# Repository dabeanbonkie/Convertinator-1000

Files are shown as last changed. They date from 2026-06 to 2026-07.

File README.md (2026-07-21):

# Convertinator 1000 Showcase

Convertinator Zine

# Description
The Convertinator 1000 is a basic power supply that converts voltage from a USB-C (5V) to 1.2V, 3.3V, 12V & 24V, also featuring an output for 5V. It has the input as the USB-C and the outputs as dupont headers as its main use is for prototyping small cicuits and basic breadboarding. It isnt made to handle strong current but the 12V & 24V connections should be able to handle a bit more.

# Reason
I designed this as a project that i could maybe use in the future when doing smaller projects as i get more and more proficient in hardware. Its not intended to run anything too heavy but can handle basic circuitly which is all I would need it for. It also worked perfectly as a project to do while parts for other projects were printing.

# Usage
To use the Convertinator 1000, take a USB-C plugged into any socket (as long as it supplies 5V) and plug it into the USB-C component on the Convertinator 1000. From there, take two dupont wires and connect them to the two headers for each voltage. One header is for the output voltage which on each connection is the header on the left, and the other is the ground which is always on the right. I highly advise you NOT to run anything above 1A on the 1.2V, 3.3V & 5V headers and NOT anything above 1.8A on the 12V & 24V headers.

# Assembly
Putting all the parts together is easy as can be. Since i figured this power supply wouldnt be moving much i havent mounted the pcb. So to assemble the Convertinator 1000, just print both components, put the pcb in the shell making sure all the gubbins on the bottom of the pcb cleanly fit into the groves on the bottom of the shell. Then mount the lid to the shell using a simple nut and bolt (4.8 mm) on the mounting holes on both parts. Then its all complete.

Here is how the pcb should be placed from the bottom of the shell:



# PCB schematic



# PCB editor 



# Onshape Link
https://cad.onshape.com/documents/8818f429682032fa239a6543/w/3c67bc1c1aed2304218f7515/e/04401e7b527ba54e698f04d5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

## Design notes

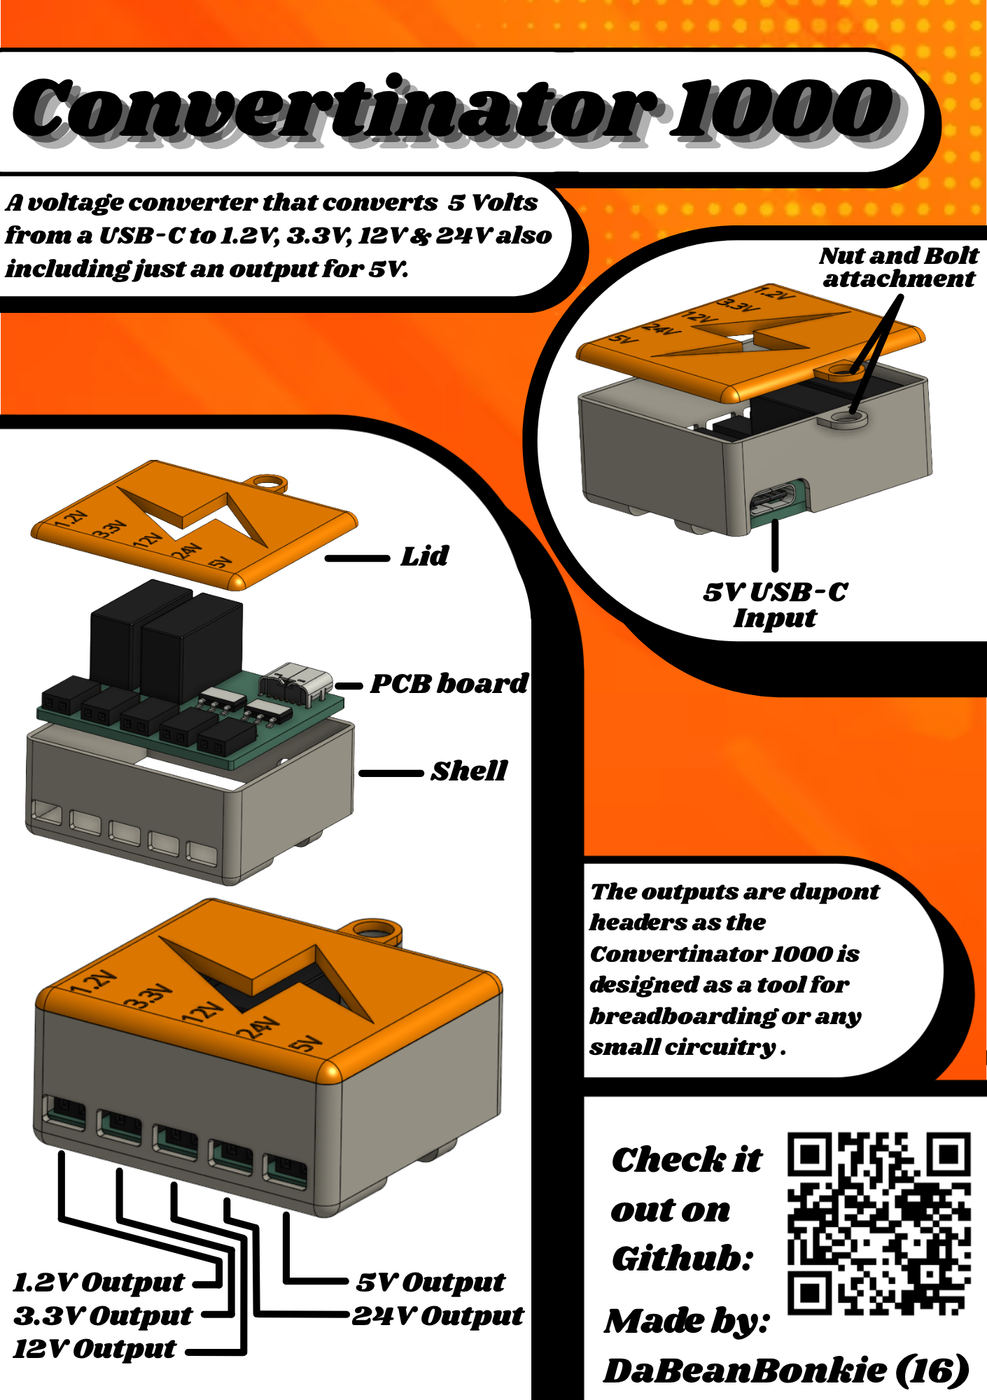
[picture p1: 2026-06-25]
Convertinator Zine.png

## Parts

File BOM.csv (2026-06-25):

Reference | Qty | Value | DNP | Exclude from BOM | Exclude from Board | Footprint | Datasheet | LCSC Link | unit price | price for all units | Total cost of pcb production (JLCPCB)
C4,C5 | 2 | C |  |  |  | Capacitor_SMD:C_0201_0603Metric | https://www.lcsc.com/datasheet/C25054.pdf | https://www.lcsc.com/product-detail/C25054.html?s_z=n_q_0201WMJ010JTEE | $ 0.001 | $ 0.002
J1 | 1 | USB_C_Receptacle_PowerOnly_6P |  |  |  | Connector_USB:USB_C_Receptacle_GCT_USB4125-xx-x-0190_6P_TopMnt_Horizontal | https://www.usb.org/sites/default/files/documents/usb_type-c.zip | https://www.lcsc.com/product-detail/C2988369.html?s_z=n_q_t_usb%2520c%2520female | $0.0864 | $0.0864,
J2,J3,J5,J6,J7 | 5 | Conn_01x02_Socket |  |  |  | Connector_PinSocket_2.54mm:PinSocket_1x02_P2.54mm_Horizontal |  | https://www.lcsc.com/product-detail/C49661.html?s_z=n_q_C49661&globalKeyword=C49661 | $ 0.0642 | 0.321,
U1 | 1 | AMS1117-3.3 |  |  |  | Package_TO_SOT_SMD:SOT-223-3_TabPin2 | http://www.advanced-monolithic.com/pdf/ds1117.pdf | https://www.lcsc.com/product-detail/C6186.html?s_z=n_q_AMS1117-3.3 | $ 0.1994 | $ 0.1994,
U4 | 1 | TMR_1-0512 |  |  |  | Converter_DCDC:Converter_DCDC_TRACO_TMR-1-xxxx_Single_THT | https://www.tracopower.com/sites/default/files/products/datasheets/tmr1_datasheet.pdf | https://www.lcsc.com/product-detail/C5962267.html?s_z=n_q_TMR_1-0512 | $ 13.8133 | $13.8133,
U5 | 1 | TMR_1-0515 |  |  |  | Converter_DCDC:Converter_DCDC_TRACO_TMR-1-xxxx_Single_THT | https://www.tracopower.com/sites/default/files/products/datasheets/tmr1_datasheet.pdf | https://www.lcsc.com/product-detail/C7362911.html?s_z=n_q_TMR_1-0515 | $ 22.9930 | $ 22.9930,
U6 | 1 | AP7361C-12E |  |  |  | Package_TO_SOT_SMD:SOT-223-3_TabPin2 | https://www.diodes.com/assets/Datasheets/AP7361C.pdf | https://www.lcsc.com/product-detail/C7076956.html?s_z=n_q_AP7361C-12E | $ 0.2738 | $ 0.2738,
Full PCB (Populated) |  |  |  |  |  |  |  |  |  |  | $127.01

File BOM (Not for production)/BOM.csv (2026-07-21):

Designator | Footprint | Quantity | Value | Unit cost | Total cost | Total cost (after tax) | LCSC Part # | LCSC Link | Cost PCB SMD JLCPCB (without TMR_1-0515) | Total Cost PCB Production
C4, C5 | 402 | 2 | C | $ 0.0342 | $ 1.71 | $0.80 | C1691 | https://www.lcsc.com/product-detail/C1691.html?s_z=n_q_CL10A106MQ8NNNC
J1 | USB_C_Receptacle_GCT_USB4125-xx-x-0190_6P_TopMnt_Horizontal | 1 | USB_C_Receptacle_PowerOnly_6P | $ 0.9285 | $ 0.93 | $1.13 | C3151650 | https://www.lcsc.com/product-detail/C3151650.html?s_z=n_q_x_USB4125-GF-A
J2, J3, J5, J6, J7 | PinSocket_1x02_P2.54mm_Horizontal | 5 | Conn_01x02_Socket | $ 0.1327 | $ 0.66 | $0.80 | C49326035 | https://www.lcsc.com/product-detail/C49326035.html?s_z=n_q_BX-PM2.54-1-2PWZ
R1, R2 | 402 | 2 | R | $0.0068 | $0.68 | $0.82 | C25905 | https://www.lcsc.com/product-detail/C25905.html?s_z=n_q_0402WGF5101TCE
U1 | SOT-223-3_TabPin2 | 1 | AMS1117-3.3 | $ 0.2004 | $ 1.00 | $ 1.21 | C6186 | https://www.lcsc.com/product-detail/C6186.html?s_z=n_q_AMS1117-3.3
U4 | Converter_DCDC_TRACO_TMR-1-xxxx_Single_THT | 1 | TMR_1-0512 | $ 13.8133 | $ 13.8133 | $16.71 | C5962267 | https://www.lcsc.com/product-detail/C5962267.html?s_z=n_q_TMR_1-0512
U5 | Converter_DCDC_TRACO_TMR-1-xxxx_Single_THT | 1 | TMR_1-0515 | $ 22.9930 | $ 22.9930 | $27.82 | C7362911 | https://www.lcsc.com/product-detail/C7362911.html?s_z=n_q_TMR_1-0515
U6 | SOT-223-3_TabPin2 | 1 | AP7361C-12E | $ 0.2738 | $ 1.37 | $1.66 | C7076956 | https://www.lcsc.com/product-detail/C7076956.html?s_z=n_q_AP7361C-12E
PCB (no TMR_1-0515) |  |  |  |  |  |  |  |  | $111.46
PCB (Complete) |  |  |  |  |  |  |  |  |  | $134.45

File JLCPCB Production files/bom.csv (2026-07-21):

Designator | Footprint | Quantity | Value | LCSC Part #
C4, C5 | 0402 | 2 | C
J1 | USB_C_Receptacle_GCT_USB4125-xx-x-0190_6P_TopMnt_Horizontal | 1 | USB_C_Receptacle_PowerOnly_6P
J2, J3, J5, J6, J7 | PinSocket_1x02_P2.54mm_Horizontal | 5 | Conn_01x02_Socket
R1, R2 | 0402 | 2 | R
U1 | SOT-223-3_TabPin2 | 1 | AMS1117-3.3
U4 | Converter_DCDC_TRACO_TMR-1-xxxx_Single_THT | 1 | TMR_1-0512
U5 | Converter_DCDC_TRACO_TMR-1-xxxx_Single_THT | 1 | TMR_1-0515
U6 | SOT-223-3_TabPin2 | 1 | AP7361C-12E

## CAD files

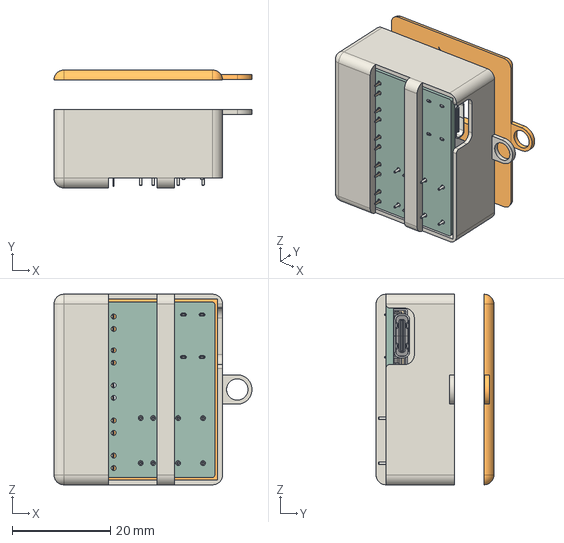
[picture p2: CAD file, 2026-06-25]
Convertinator 1000 STEP file/Convertinator 1000.step
40.3 x 24.0 x 38.8 mm

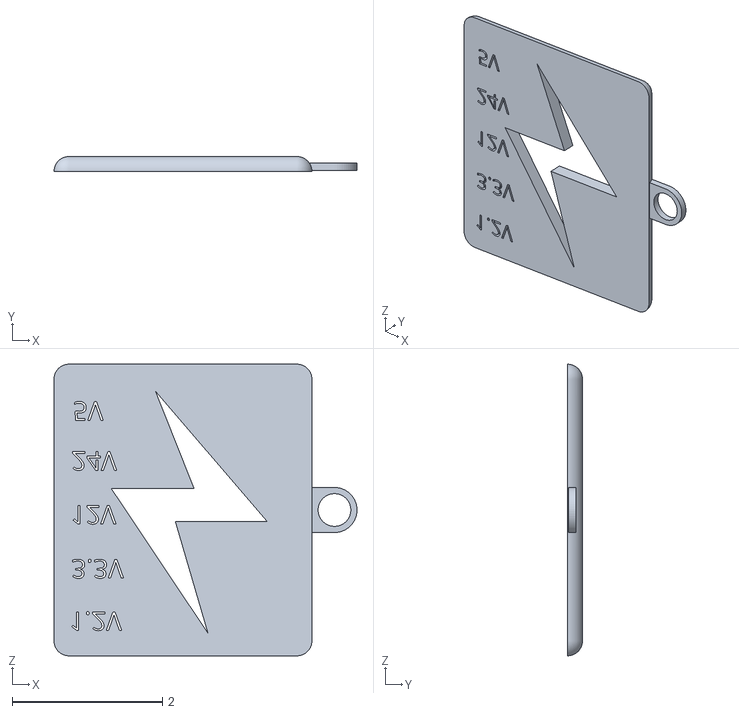
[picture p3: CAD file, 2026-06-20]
Convertinator 1000 STL Files/Top-lid-Convertinator-1000.stl
4.03 x 0.2 x 3.88

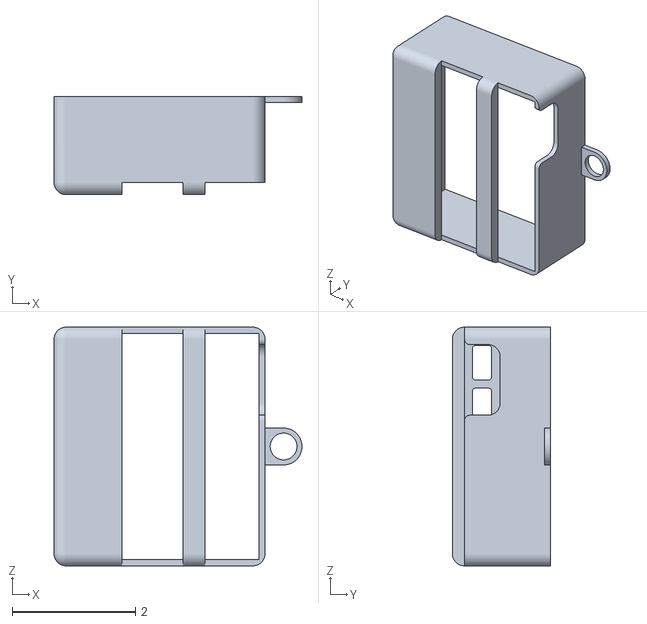
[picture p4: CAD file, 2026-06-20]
Convertinator 1000 STL Files/Shell-Convertinator-1000.stl
4.03 x 1.60 x 3.88

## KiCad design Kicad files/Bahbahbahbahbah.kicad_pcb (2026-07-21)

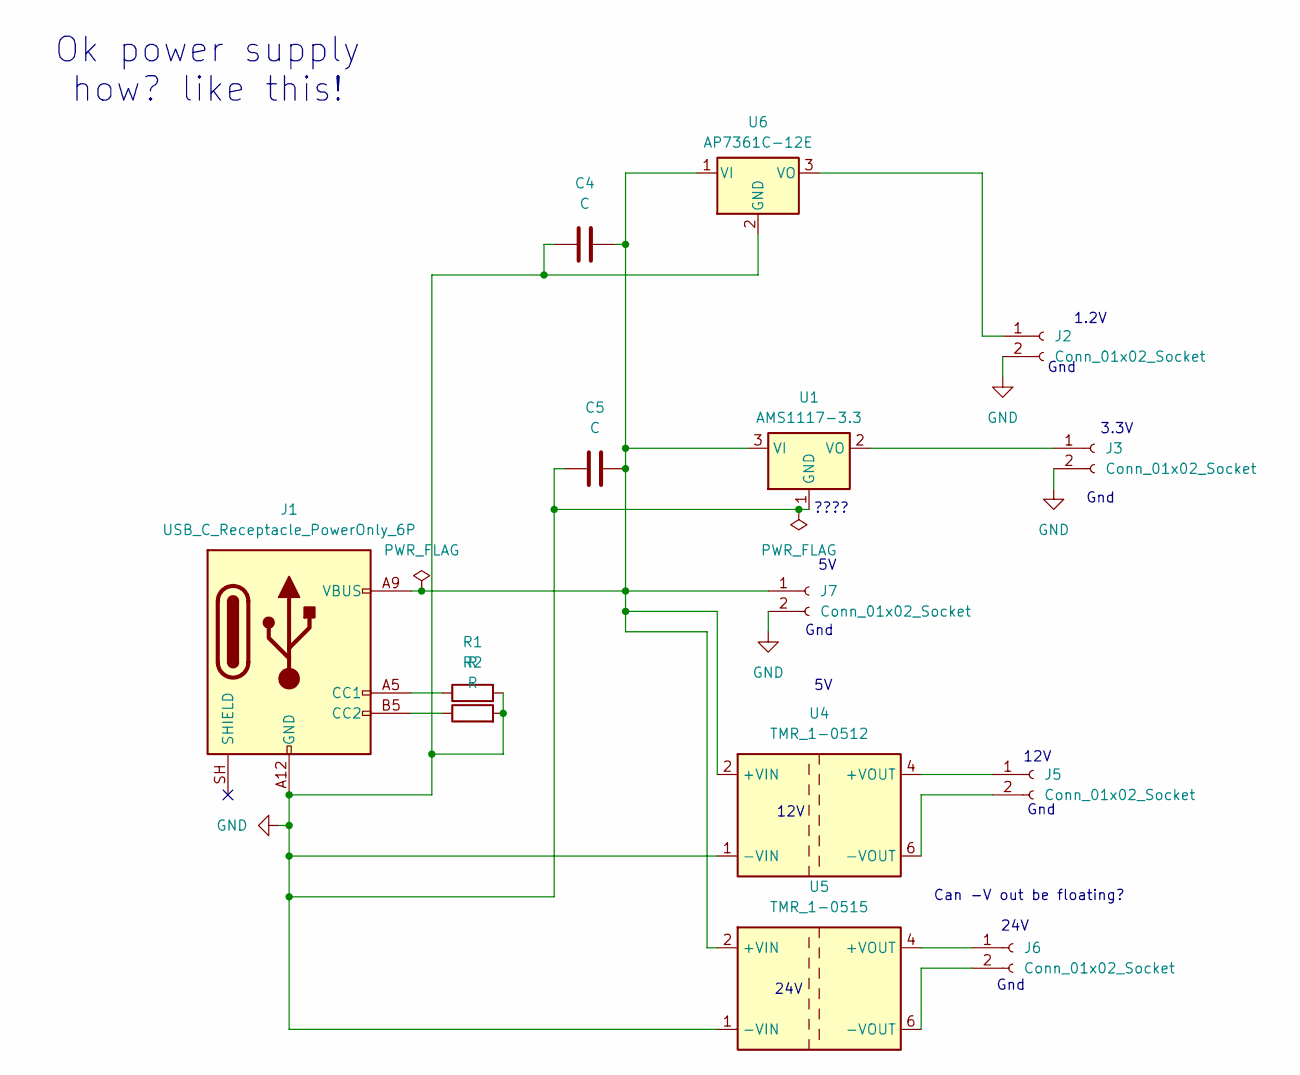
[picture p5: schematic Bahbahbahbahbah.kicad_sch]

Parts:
C4, C5: C; C_0402_1005Metric
J1: USB_C_Receptacle_PowerOnly_6P; USB_C_Receptacle_GCT_USB4125-xx-x-0190_6P_TopMnt_Horizontal
J2, J3, J5, J6, J7: Conn_01x02_Socket; PinSocket_1x02_P2.54mm_Horizontal
R1, R2: R; R_0402_1005Metric
U1: AMS1117-3.3; SOT-223-3_TabPin2
U4: TMR_1-0512; Converter_DCDC_TRACO_TMR-1-xxxx_Single_THT
U5: TMR_1-0515; Converter_DCDC_TRACO_TMR-1-xxxx_Single_THT
U6: AP7361C-12E; SOT-223-3_TabPin2

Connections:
GND: C4.1, C5.1, J1.A12 (GND), J1.B12 (GND), J2.2, J3.2, J7.2, R1.2, R2.2, U1.1 (GND), U4.1 (-VIN), U5.1 (-VIN), U6.2 (GND)
unnamed: J1.A5 (CC1), R1.1
unnamed: J1.B5 (CC2), R2.1
unnamed: J2.1, U6.3 (VO)
unnamed: J3.1, U1.2 (VO)
unnamed: J5.1, U4.4 (+VOUT)
unnamed: J5.2, U4.6 (-VOUT)
unnamed: J6.1, U5.4 (+VOUT)
unnamed: J6.2, U5.6 (-VOUT)
unnamed: C4.2, C5.2, J1.A9 (VBUS), J1.B9 (VBUS), J7.1, U1.3 (VI), U4.2 (+VIN), U5.2 (+VIN), U6.1 (VI)

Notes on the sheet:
Can -V out be floating?
Ok power supply how? like this!
????
Gnd
12V
1.2V
3.3V
24V

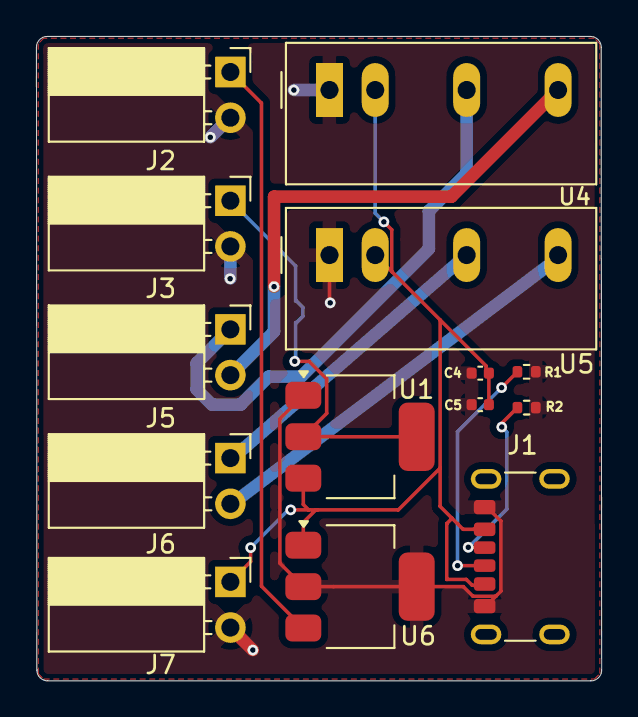
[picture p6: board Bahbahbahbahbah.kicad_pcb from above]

Board: 2 copper layers, 31.4 x 35.8 mm, 14 parts (0 on the bottom side), 10 nets.

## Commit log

2026-06-20 Create STL- Files Shell & Lid Convertinator 1000
2026-06-21 Create PCB Gerber files Convertinator-1000
2026-07-21 I eat dirt
    [bom.csv, positions.csv]
